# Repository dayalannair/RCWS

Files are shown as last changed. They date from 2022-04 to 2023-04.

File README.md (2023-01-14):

# Radar Intersection Collision Prediction System (R-ICPS)

### NB - Offline python proc exists in the folder

## TO DO

1. Modify Python algorithm with SOCA CFAR and PFa = 0.008
2. Get more IQ data
3. Test real time Python after update
4. Design chapter
5. Results chapter
6. Apply Lit review fixes after Yunus reviews

## Report notes

- Focus on MATLAB stuff in the 'advanced' directory of traingle FMCW DSP
- Add waterfall and other plot from pulse mean canceller and compare pre and post calibration
- finish up results, then either neaten or add to design and lit review
- Check with supervisors etc
- Rather have slightly more words than just on the verge of enough

## Task list

- [ ] Add all work to report - remember to use issues and discussions from old repo
- [X] Improve bin method by restricting 'search' area for triangle modulation/ I.e. based on fbd, where can we expect fbu?
- [X] Improve Python OS CFAR
- [X] Test full Python realtime version on PC and RPI
- [X] Integrate Pi camera and show real time plots of spectra, results, and video (similar to MATLAB offline processing)
- [X] Modify real time Python program to work with two uRADs
- [X] Modify dual radar Python program to incorporate two cameras. Pi can support one Pi cam and one USB camera
- [ ] Consider a Pi network - control and sensor nodes
- [ ] Create condensed Python program (no GUI) as required by the prototype
- [ ] Test system - both GUI and no GUI - on road side
- [ ] Install system on car and test in controlled and (or) road environments
- [ ] Neaten simulations and present in report
- [ ] clean up/neaten repository

### Link to data storage:
https://uctcloud-my.sharepoint.com/:f:/g/personal/nrxday001_myuct_ac_za/EjFL7omlg09PrdxWb3c22k4BgLi7pwkYM-8y16FP6_n1MA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

### Notes: 
- add data and library folders to MATLAB path after clone not needed if addpath() is called in each script
- Data collection/radar programs are in data/urad_usb
- make sure textfiles/data is never committed - deletion will not remove data from version history and so increase repo size
- in the event a repo gets too large, use filter-repo (3rd party program) to filter *.txt etc and push to a new repo
- USB for linux found using lsusb. Currently using ACM0. Device is infineon technologies

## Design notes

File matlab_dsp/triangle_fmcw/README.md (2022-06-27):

# Current state directory

This directory holds all of the latest/current files being tested/designed/used. This includes simulation (sm),
real data (rd), etc.

## cfar_sm --> Simulation using the CFAR detection algorithm
Note: the algorithm is still under test

The code outline follows:

1. Create radar object
2. Create target and environment objects
3. Simulation loop
    - Currently, the loop is run for a total of 1 second
    - the received echo is processed every t_step seconds
    - this means that in the intermediate intervals, the data is not observed, i.e. the target is made to hop
    from point to point, with a constant velocity
    - The simulation should be tested at the max update rate, which will generate a good amount of data
    - Decimation is used to simulate ADC sampling. The wave sample rate is related to the carrier as it needs
    to simulate this high freqeuncy.

4. Range and velocity estimates are plotted
5. Spectrums and signals plotted

## cfar_rd --> Real data processing using the CFAR detection algorithm
Similar to the above but for real data. Must use the data timestamps to get an average t_step time to use in simulation.
# Need to store data in an array before writing to file! and collect new data this way

## Rootmusic programs

These use the rootmusic algorithm instead of CFAR. Need to get it working on real data.

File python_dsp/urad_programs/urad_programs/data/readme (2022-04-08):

Data follows the following format:
Target number	Distance (m)	Velocity (m/s)	SNR (dB)

The file names correspond to the uRAD USB v1.2 and uRAD RPi v1.1 device measurements. Note that uRAD USB runs SDK 1.1 whereas uRAD RPi runs SDK v1.0.
Facing the device from the RPi power port, the uRAD USB is the left-hand side radar and the uRAD RPi is the right-hand side radar.
The program currently overwrites the last record session. If you would like to permanently save data, rename the file and/or copy to a different directory.

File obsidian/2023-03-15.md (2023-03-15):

- [ ] Add FFT length vs. accuracy scatters and table to results
- [ ] Update calibration section in impl - maybe remove section and add to another, since fairly straight fwd. 
- [ ] Get impl section reviewed
- [ ] Finish lit review comments - not pressing since they seem like QOL improvs
- [ ] Simons comments on simulation and method (see canvas)

If possible, get patch ant sim working. Else, phrase it better/dont give it a section in the sim section, maybe just add the antenna pattern plots.

# Important
1. Accuracy only important for controlled tests
2. Need GPS for controlled tests
3. Dependance on range accuracy more influential as range reduced. Opposite for velocity

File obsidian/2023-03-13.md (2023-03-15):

- [ ]  Implementation chapter reviewed
- [x] Continue with lit review and sim chapter corrections
- [ ] Add list of symbols
- [x] Get raw data for target at a known distance and post proc to test windowing and for calibration
	- [x] Or not since calib not dependent on window, though cannot analys windowing here
	- [ ] get a large set of points for calib!

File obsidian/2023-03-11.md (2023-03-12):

Need to apply report changes after new developments
- [x] Square law detector not on IQ samples
- [ ] DC cancelling on IQ samples
- [ ] change PFA with square law before CFAR
- [ ] window function need changes?
- [ ] Fix colour for BD matlab python engine
- [ ] CONTINUE with CFAR comparison
- [ ] 

- [x] Changes to Python proc as applied in matlab and test
	- [ ] Need to do more testing regarding nearest range bin and LHS targets
- [ ] Complete issues above and resolve comments in design section
- [ ] Read, resolve comments, Grammarly, print Implementation and submit
- [ ] Resolve comments on Lit review and simulation sections
- [ ] 

Field testing
- [x] apply angle adjustment condition to Python
- [ ] Test in controlled env near Peralex
- [ ] One last uncontrolled and photograph the setup
- [ ]

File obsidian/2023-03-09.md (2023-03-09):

Attempt ADC mean cancellation - uRAD GUI line 611
Need to test with more data
continue addressing comments on design chapter, then pass through Grammarly and print
Address comments on other sections before sorting out the implementation section
Dont forget about the ADT sim data
And add code for AOA left side, and ensure cuter angle not needed - doubt since now all dets on left of boresight - may be able to prove 25 deg is optimal

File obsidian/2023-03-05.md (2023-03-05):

Adding printed changes to simulation section
Need to add frame sync rtproc and iq_data versions - not strictly, would be nice
One more controlled test
	- UCT
	- Somewhere else
Add new tables to the simulation section (cross over) and continue cleaning

Angle correction wrong in matlab - need to check that angle corrected values are larger than measurement

RT proc not looking good. Present offline proc results using new heatmap scheme
	- #### NB not looking good for raised tests

Video frame rate higher/faster in rt proc than iq. Likely 4thd vs 2thd. Use 2 thd iq data collection next time. 
	- Makes sense since video in same thd as radar? should be the other way round?
	- 
	Add option to record offline proc and store in data repo. Then dont need to reproc each time

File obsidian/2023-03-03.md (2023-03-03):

Note that the best rhs result is 03-03-2023: _12_52_43
- Add that to the report
- check left side
- note that this was not placed on the car

Check if placing radar on car better or worse
	- device was further from the edge of the road

Continue prepping sim section for review
Finish up results section and send for review
Then clean up implementation and design

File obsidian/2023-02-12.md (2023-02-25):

### Session 1:

- Installing Fusion360 to get CAD renderings
- Created a reduced comments file of Yunus' doc
- Lit review and methodology have the most comments to be addressed, so continue with those
- Since system works with angle adjustment, need to add adjustment to the test rig, get final set of road data and present in results section. 
- WOuld be good to get a final set of controlled results at UCT
	- Need GPS tracks + radar + speedometer
- Remember to report on the improved measurements using angle conrrections

### Session 2:

- added some info to lit review on SA statistics
- need to find analysis on intersection statistics
- need to inprove the bits from the RTMC
- added and sorted out CAD rendering in report

#### Session 3:

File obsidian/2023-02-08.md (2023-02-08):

Added the equations for the sawtooth calcs for the speed v range trade off.
	Need to refine by adding explanation
	Need to neaten and add velocity equation
	Add code snippet
Added Simon's comments here. Need to address these and Yunus' comments
Need to test different angle from left side radar tomorrow
	should be enough battery power

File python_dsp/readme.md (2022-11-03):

# Results

## offline processing

### Offline plotting raw data
- the returns of cars passing directly infront or close to the radar have a broad SNR when the Taylor window is implemented. 
- Most of the easy to see targets in the spectra are those moving away after passing the host 
- need to test Hanning window
- Many targets/ a busy road will affect detection and tracking
- add offline processing to confirm

## Real time results

Sparse due to many reflective targets
Wind?

## Call matlab engine

This can only run on a PC with MATLAB installed. The Python script reads in data from the uRAD/s and stores in a MATLAB workspace. A MATLAB processing script is called to process the data. Results are read from the workspace.

### 1. Configurable MATLAB workspace parameters
This option allows for changing the MATLAB parameters from within the Python script.

### 2. Preconfigured MATLAB workspace
A MATLAB script is used to generate all of the required variables beforehand, which are saved as a .mat file. The Python script loads this file instead of calling MATLAB functions to generate the base parameters.

### Note
The MATLAB engine takes a couple of seconds to boot

## Python plots

- These plot out the real time DSP and results thereof. 
- The plotting slows down processing
- VNC remote desktop runs very slowly
- SSH X forwarding runs slowly
- Storing as a JPEG is slow, though faster than the above methods

## Store results

- No plotting, though data is stored in arrays and finally written to a textfile. 
- Minimal effect on performance, though not as optimal as the full realtime system (no plot, no store)

## Pure system

- Only the final results are displayed.
- Results displayed in the CLI or using LEDs
- PWM to be implemented

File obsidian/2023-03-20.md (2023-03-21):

1. Simulation section
	1. For simulating patch antenna, it seems that one needs to get the microstrip design correct, and the taper must be set. In the meantime, can still attempt to get it going. 
	2. Need to address the comments on this chapter first. Leave microstrip for last
2. Results
	1. Prep section for final results
	2. Get RPI ready for final results
		1. Can measure performance/update rate so long

# 2023-03-21

Need to change proc to be in terms of 1024-point FFT

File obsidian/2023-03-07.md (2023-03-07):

[[2023-03-06]] See stuff thats here

1. Address both Yunus and Simons comments on Simulation section
	1. Look through the comments for lit review and simulation to see if anything major needs to be addressed.
2. If all is good with above, get design chapter ready for review
	1. Go through latex doc
	2. Grammarly
	3. Print and read through + edit
3. Once design chapter in for review, address comments to lit review and simulation chapters
4. Get final results
	1. add check for AOA based on angle adjustment and test outside work
	2. More controlled experiments
	3. One more uncontrolled - take PICTURES for both
	4. Write up section and send for review
5. Lastly, get implementation section reviewed
6. Get overall impression, then get whole thing reviewed one more time.

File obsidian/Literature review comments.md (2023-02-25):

Things to do:

1. More south african context - move from intro 
2. Current systems - summarise functionality and how well they work. Also costs
3. V2I 
	1. Strengths + assumptions
	2. weaknesses
4. V2V
	1. strengths + assumptions
	2. weaknesses
5. Standalone
	1. radar tracking
		1. key params of the radar
	2. Clarify link between Kalman: 
		1. Gate method
		2. Tracking is needed~
6. #### Crit review
	1. Clear link 
	2. highlight weaknesses
3. #### Automotive radar system
	Factors contributing to performance and ref - need to find out if ref sections or cite. think the former

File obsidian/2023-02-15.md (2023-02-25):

Remember to mention how Python program is structured: 
	All variants pull from a common processing library

Did admin for ethics and prog report

Continue in the afternoon on comments
printing general papers on V2V and V2I

## Comments for Yunus to address:

- I believe the paragraphs detailing collision warning and assistance covers functionality?
- The next paragraph explains conditions in which performance is reduced

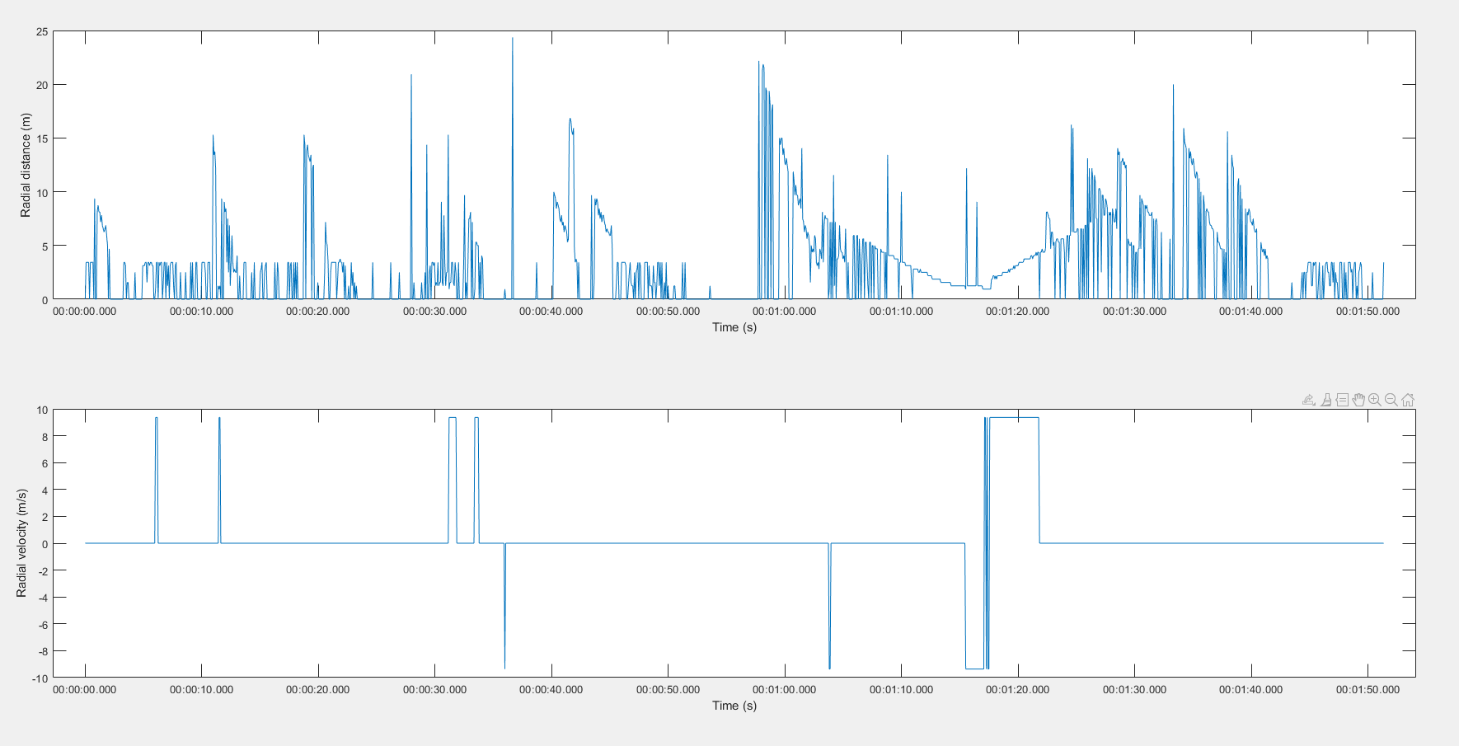
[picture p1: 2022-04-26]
python_dsp/urad_programs/graphs/mydsp_mti_gui.png

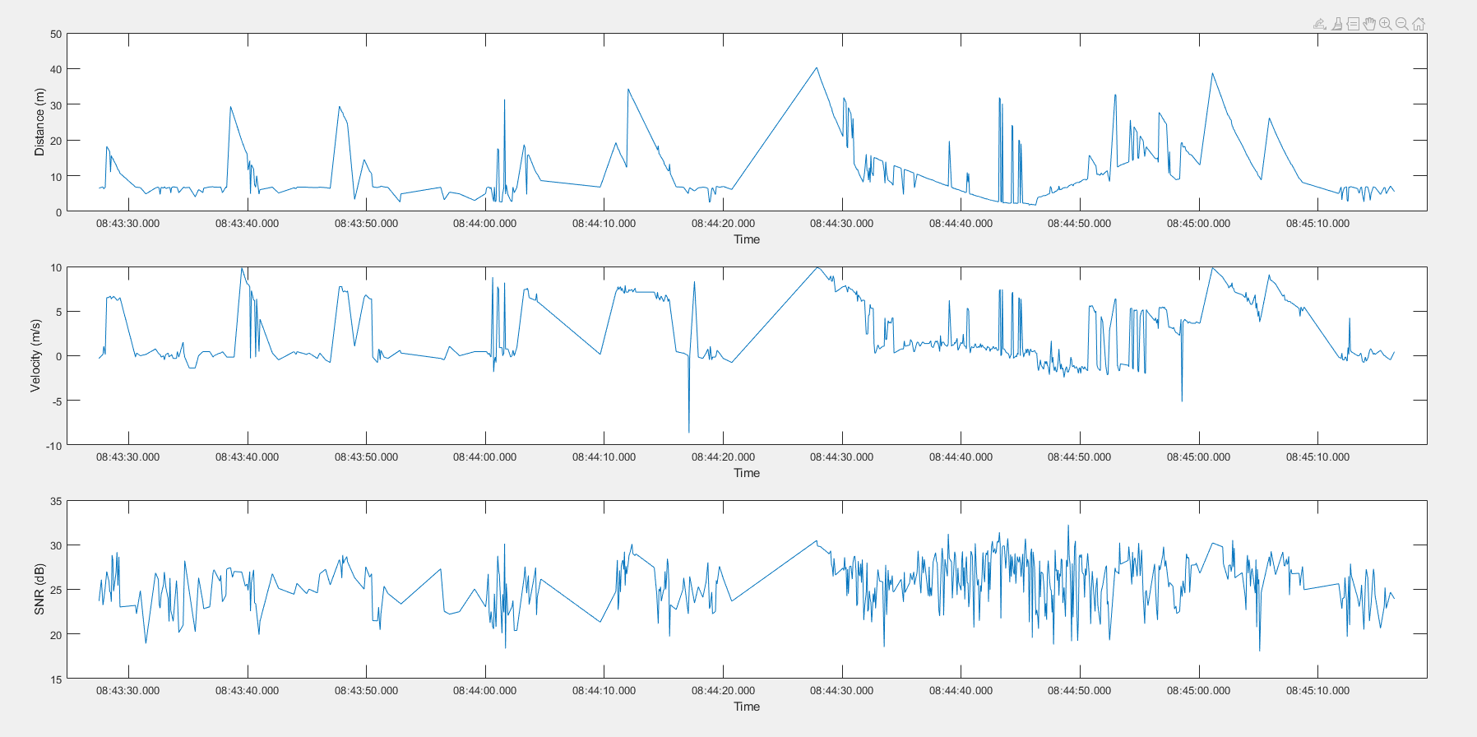
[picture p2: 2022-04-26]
python_dsp/urad_programs/graphs/urad_dsp_mti_gui.png

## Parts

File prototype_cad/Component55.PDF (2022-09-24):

SOLIDWORKS Student Edition. For Academic Use Only.

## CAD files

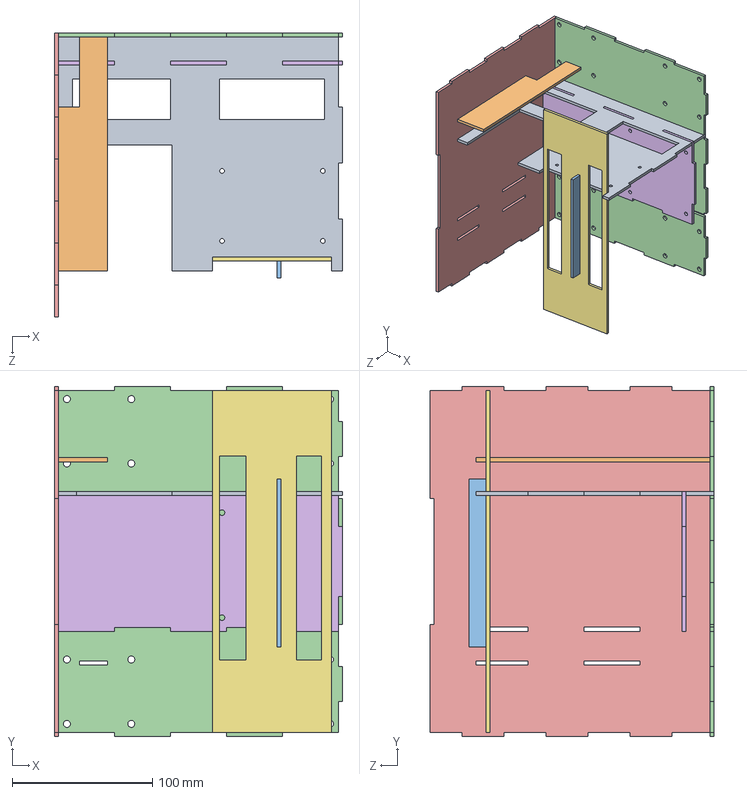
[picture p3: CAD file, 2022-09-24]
prototype_cad/prototype1_ICPS v98.SLDASM
206.0 x 250.0 x 203.0 mm
cam_secure
bottom
back
pi_holder
cam_holder (1)

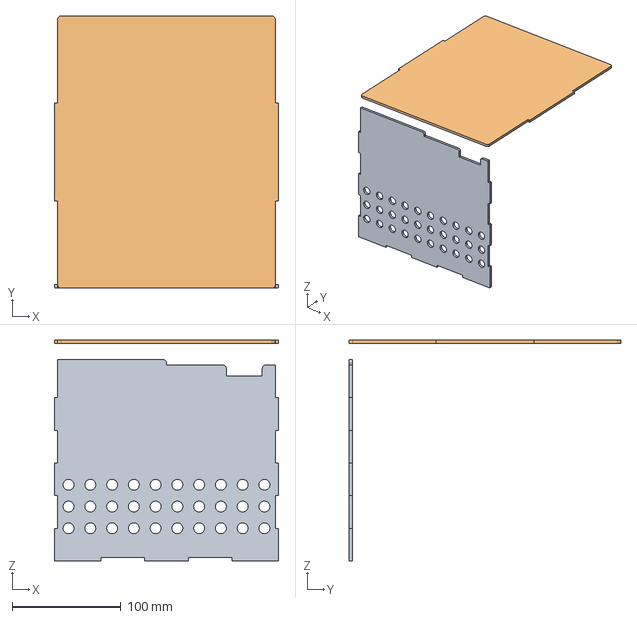
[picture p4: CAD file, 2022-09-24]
prototype_cad/top_and_side.step
206.0 x 250.0 x 203.0 mm
right
top

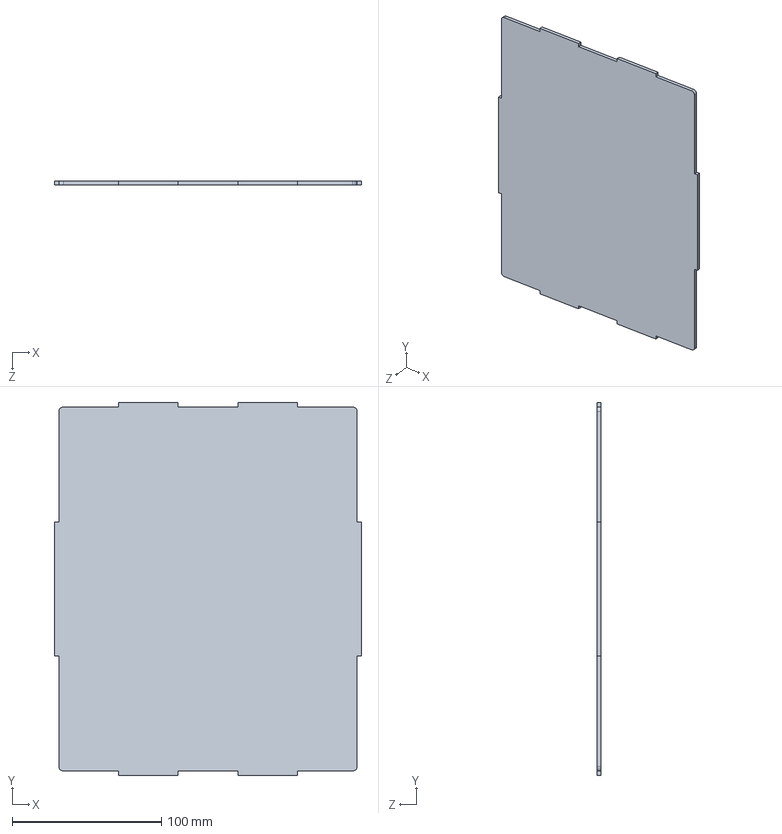
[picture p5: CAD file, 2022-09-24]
prototype_cad/top new.SLDPRT
206.0 x 250.0 x 3.00 mm

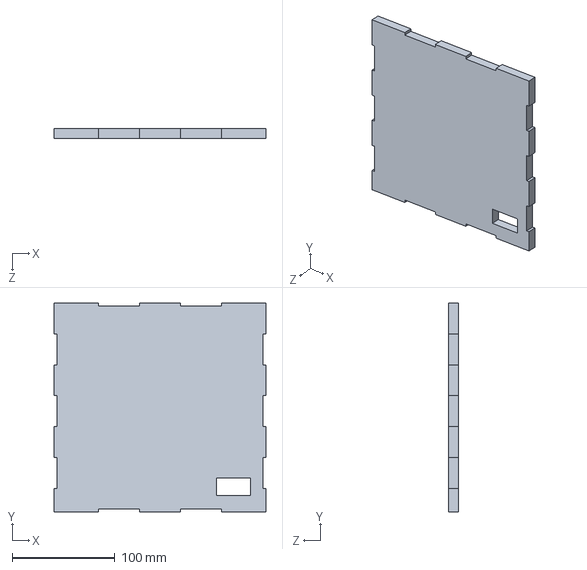
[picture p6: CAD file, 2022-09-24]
prototype_cad/side.SLDPRT
206.0 x 203.0 x 10.0 mm

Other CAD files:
prototype_cad/rails.sldasm
prototype_cad/pi_holder.sldprt
prototype_cad/cam_holder (1).sldprt
prototype_cad/back.sldprt
prototype_cad/right.sldprt
prototype_cad/top.sldprt
prototype_cad/cam_secure.sldprt
prototype_cad/Component55.sldprt
prototype_cad/Component54.sldprt
prototype_cad/bottom.sldprt
prototype_cad/Component54.SLDDRW
prototype_cad/Component55.SLDDRW
prototype_cad/back.SLDDRW
prototype_cad/bottom.SLDDRW
prototype_cad/cam_holder (1).SLDDRW
prototype_cad/cam_secure.SLDDRW
prototype_cad/side.SLDDRW
prototype_cad/top new.DXF
prototype_cad/top new.SLDDRW
prototype_cad/top_and_side.SLDASM

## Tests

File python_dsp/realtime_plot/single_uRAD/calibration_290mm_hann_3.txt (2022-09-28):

1.5920351119281047
1.8369635906862747
2.0818920694444447
1.8369635906862747
1.9594278300653596
4.041319899509804
3.5514629419934636
2.6942132663398697
1.9594278300653596
2.326820548202615
3.1840702238562093
2.326820548202615
3.4289987026143787
2.326820548202615
3.673927181372549
1.5920351119281047
1.9594278300653596
1.9594278300653596
1.8369635906862747
2.2043563088235296
1.8369635906862747
1.9594278300653596

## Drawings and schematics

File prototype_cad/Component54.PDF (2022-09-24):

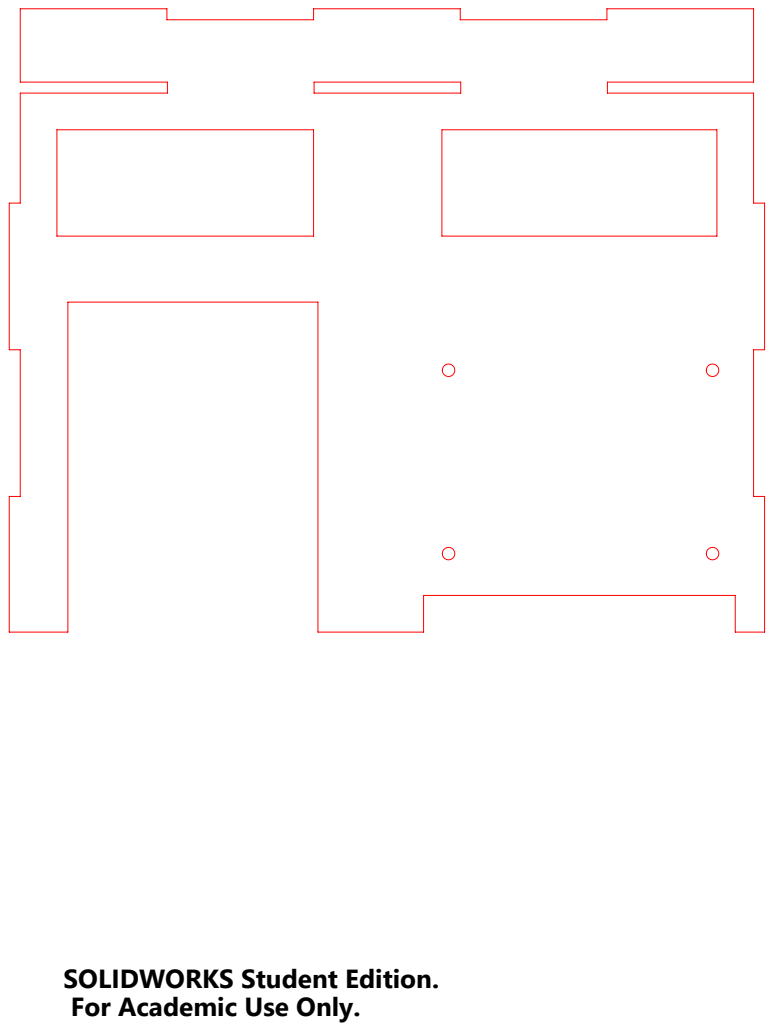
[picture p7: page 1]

SOLIDWORKS Student Edition.
For Academic Use Only.

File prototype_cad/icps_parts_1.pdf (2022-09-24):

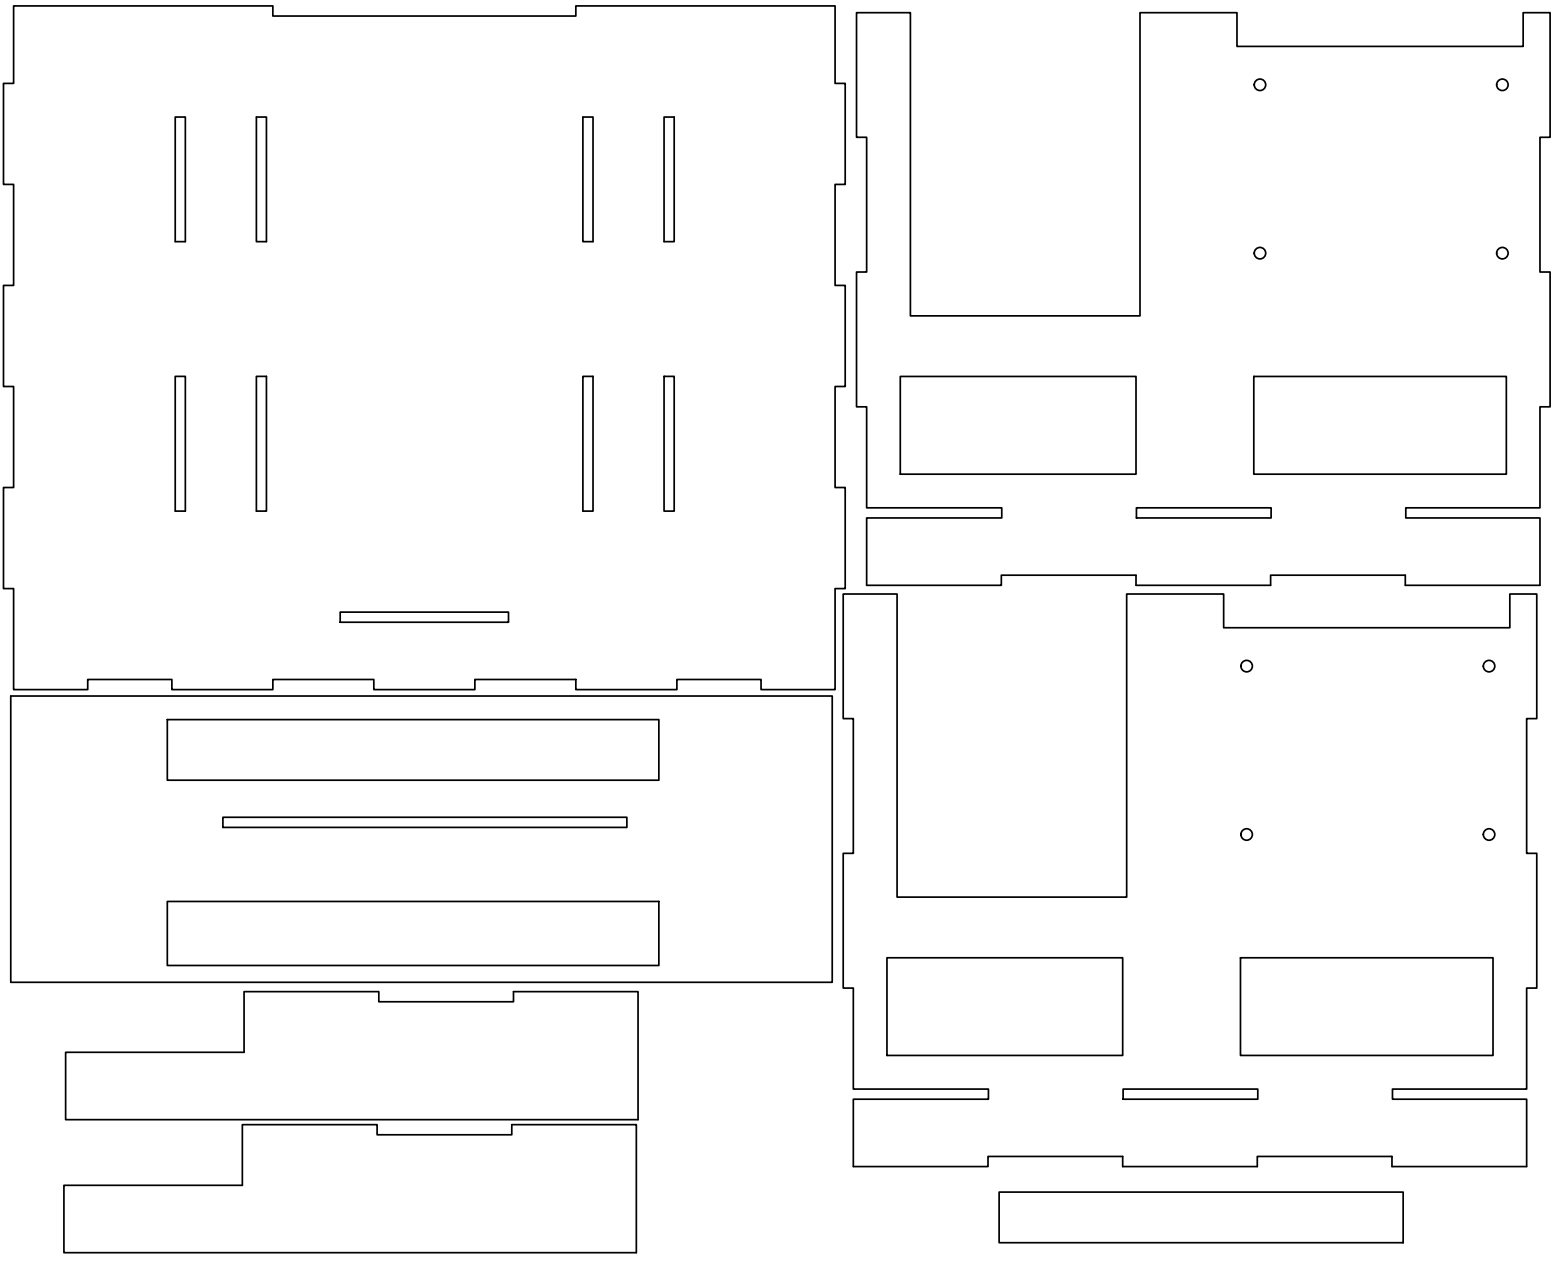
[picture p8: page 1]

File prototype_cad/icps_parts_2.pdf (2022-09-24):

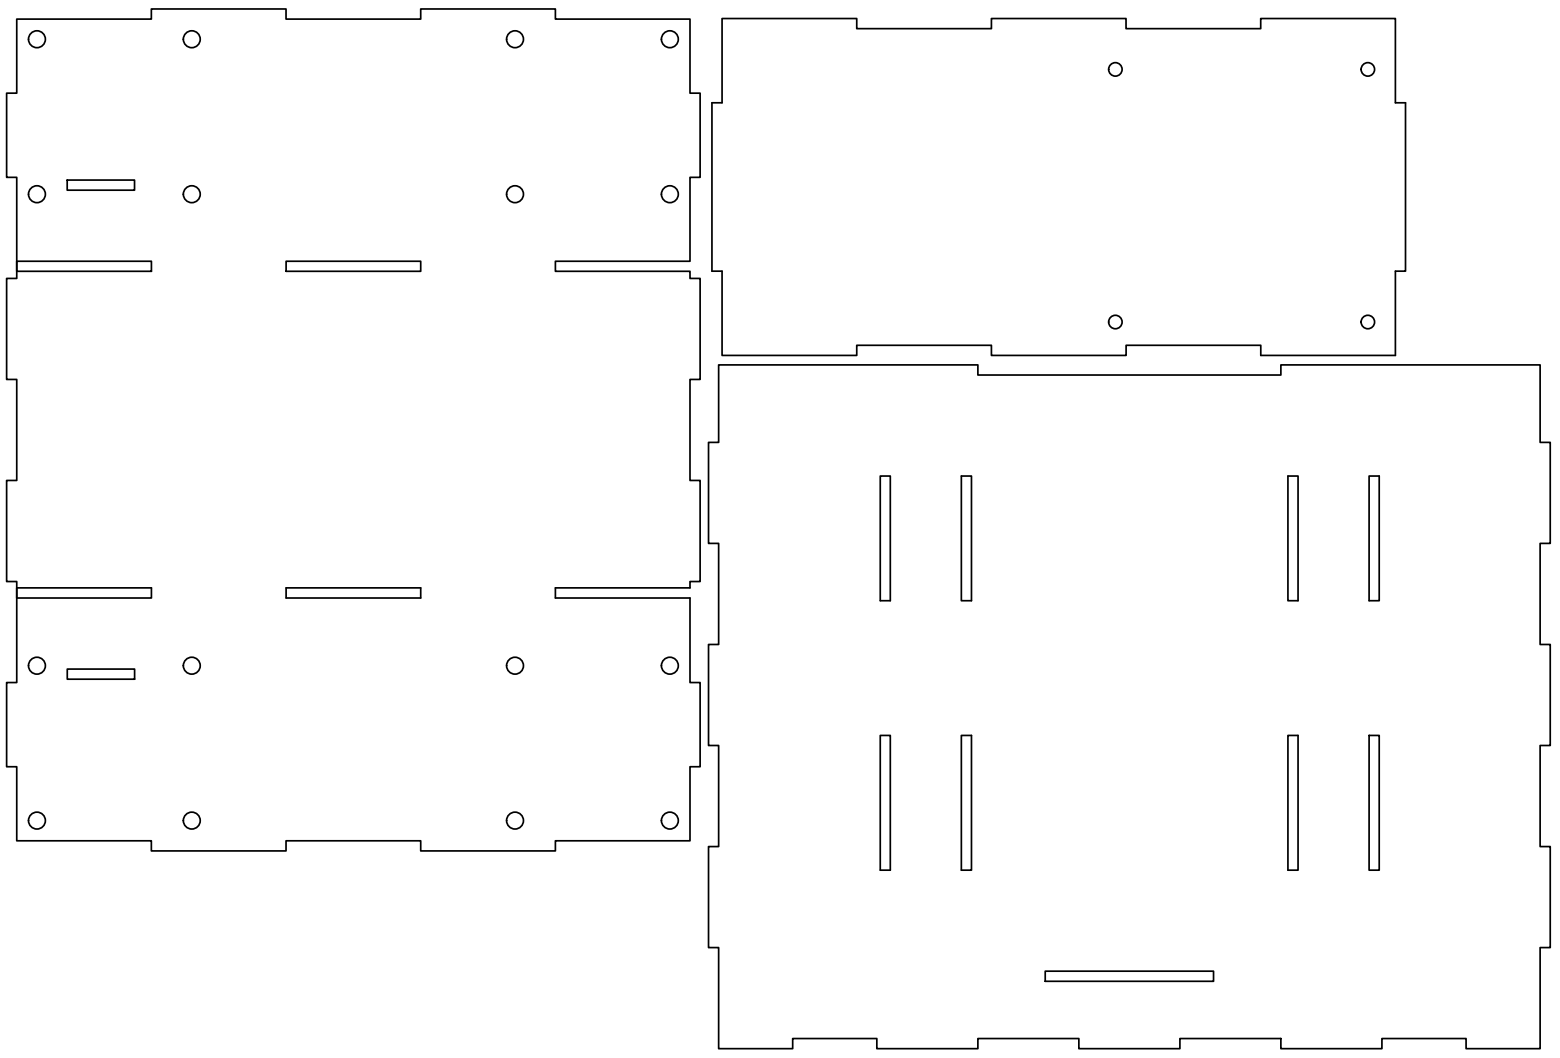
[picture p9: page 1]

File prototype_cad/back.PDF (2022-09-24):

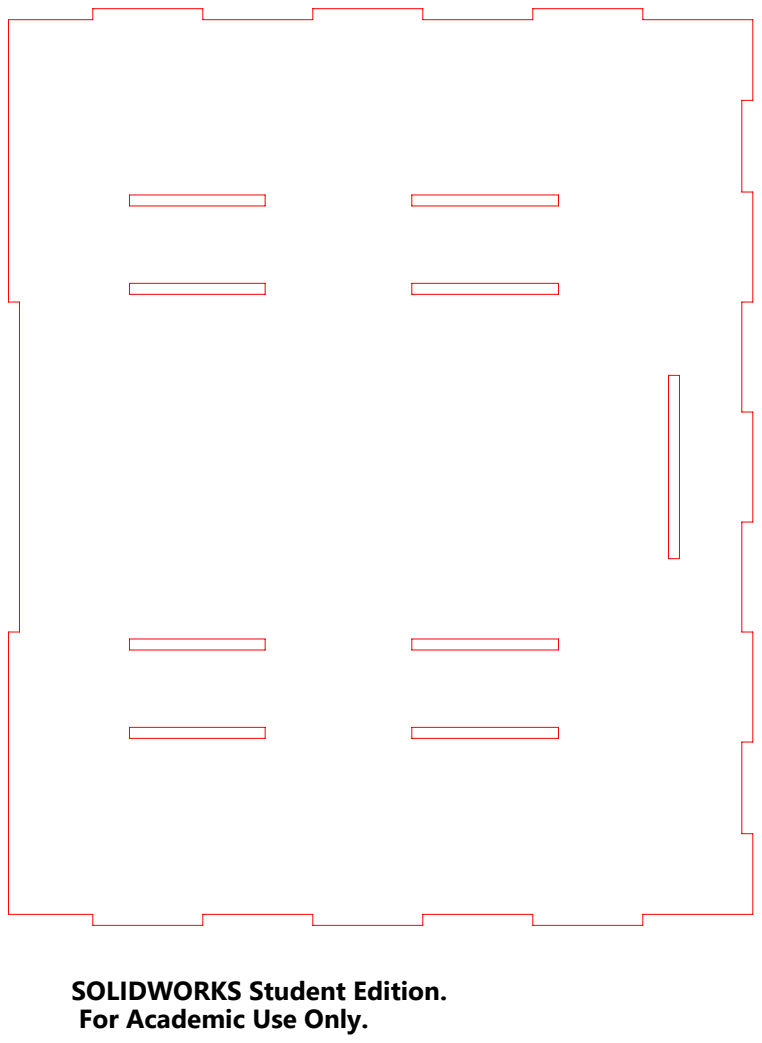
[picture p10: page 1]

SOLIDWORKS Student Edition.
For Academic Use Only.

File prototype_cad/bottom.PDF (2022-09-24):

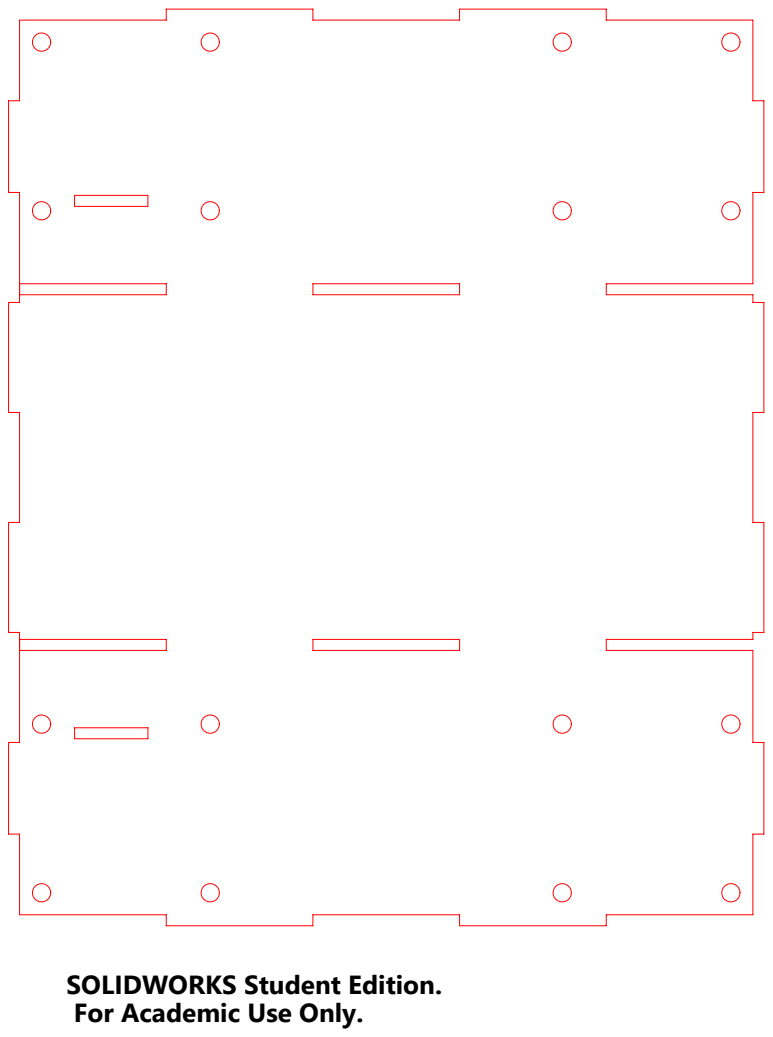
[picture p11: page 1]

SOLIDWORKS Student Edition.
For Academic Use Only.

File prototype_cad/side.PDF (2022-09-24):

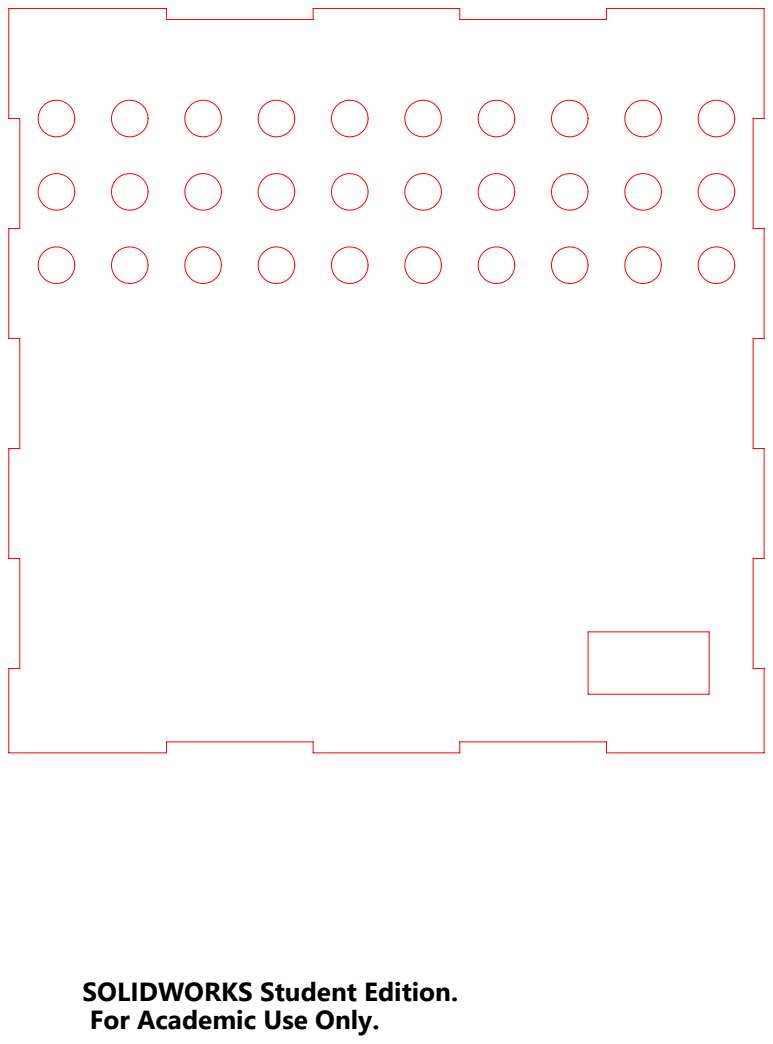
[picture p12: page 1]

SOLIDWORKS Student Edition.
For Academic Use Only.

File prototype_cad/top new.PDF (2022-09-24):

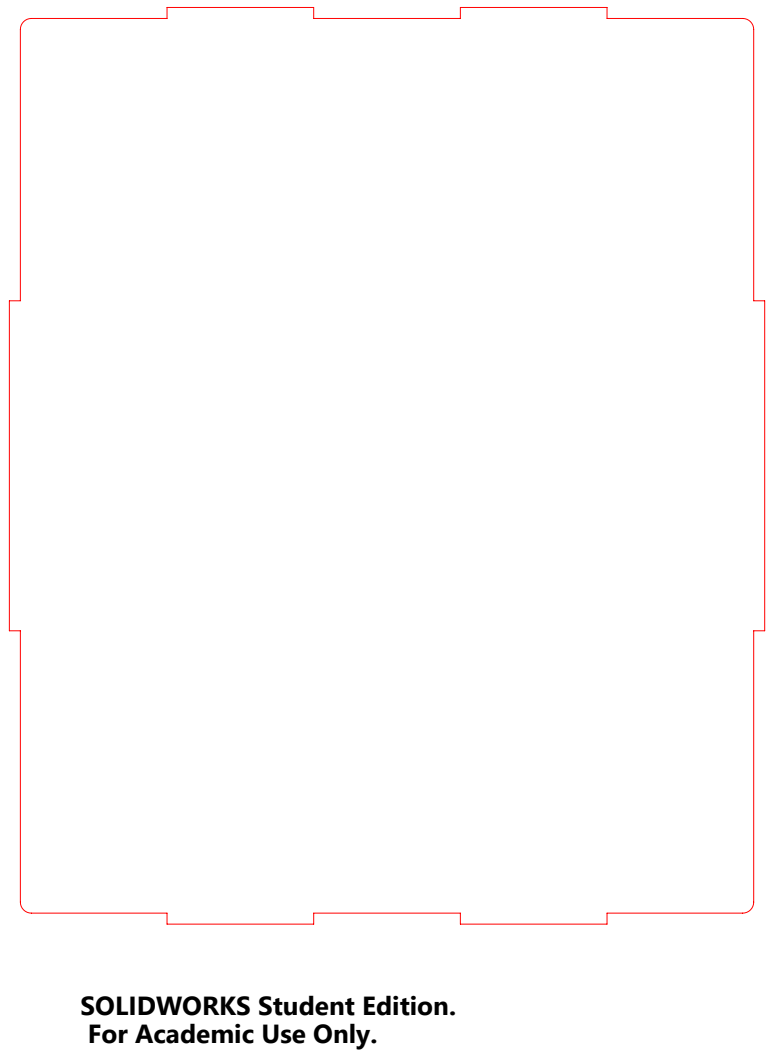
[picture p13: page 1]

SOLIDWORKS Student Edition.
For Academic Use Only.

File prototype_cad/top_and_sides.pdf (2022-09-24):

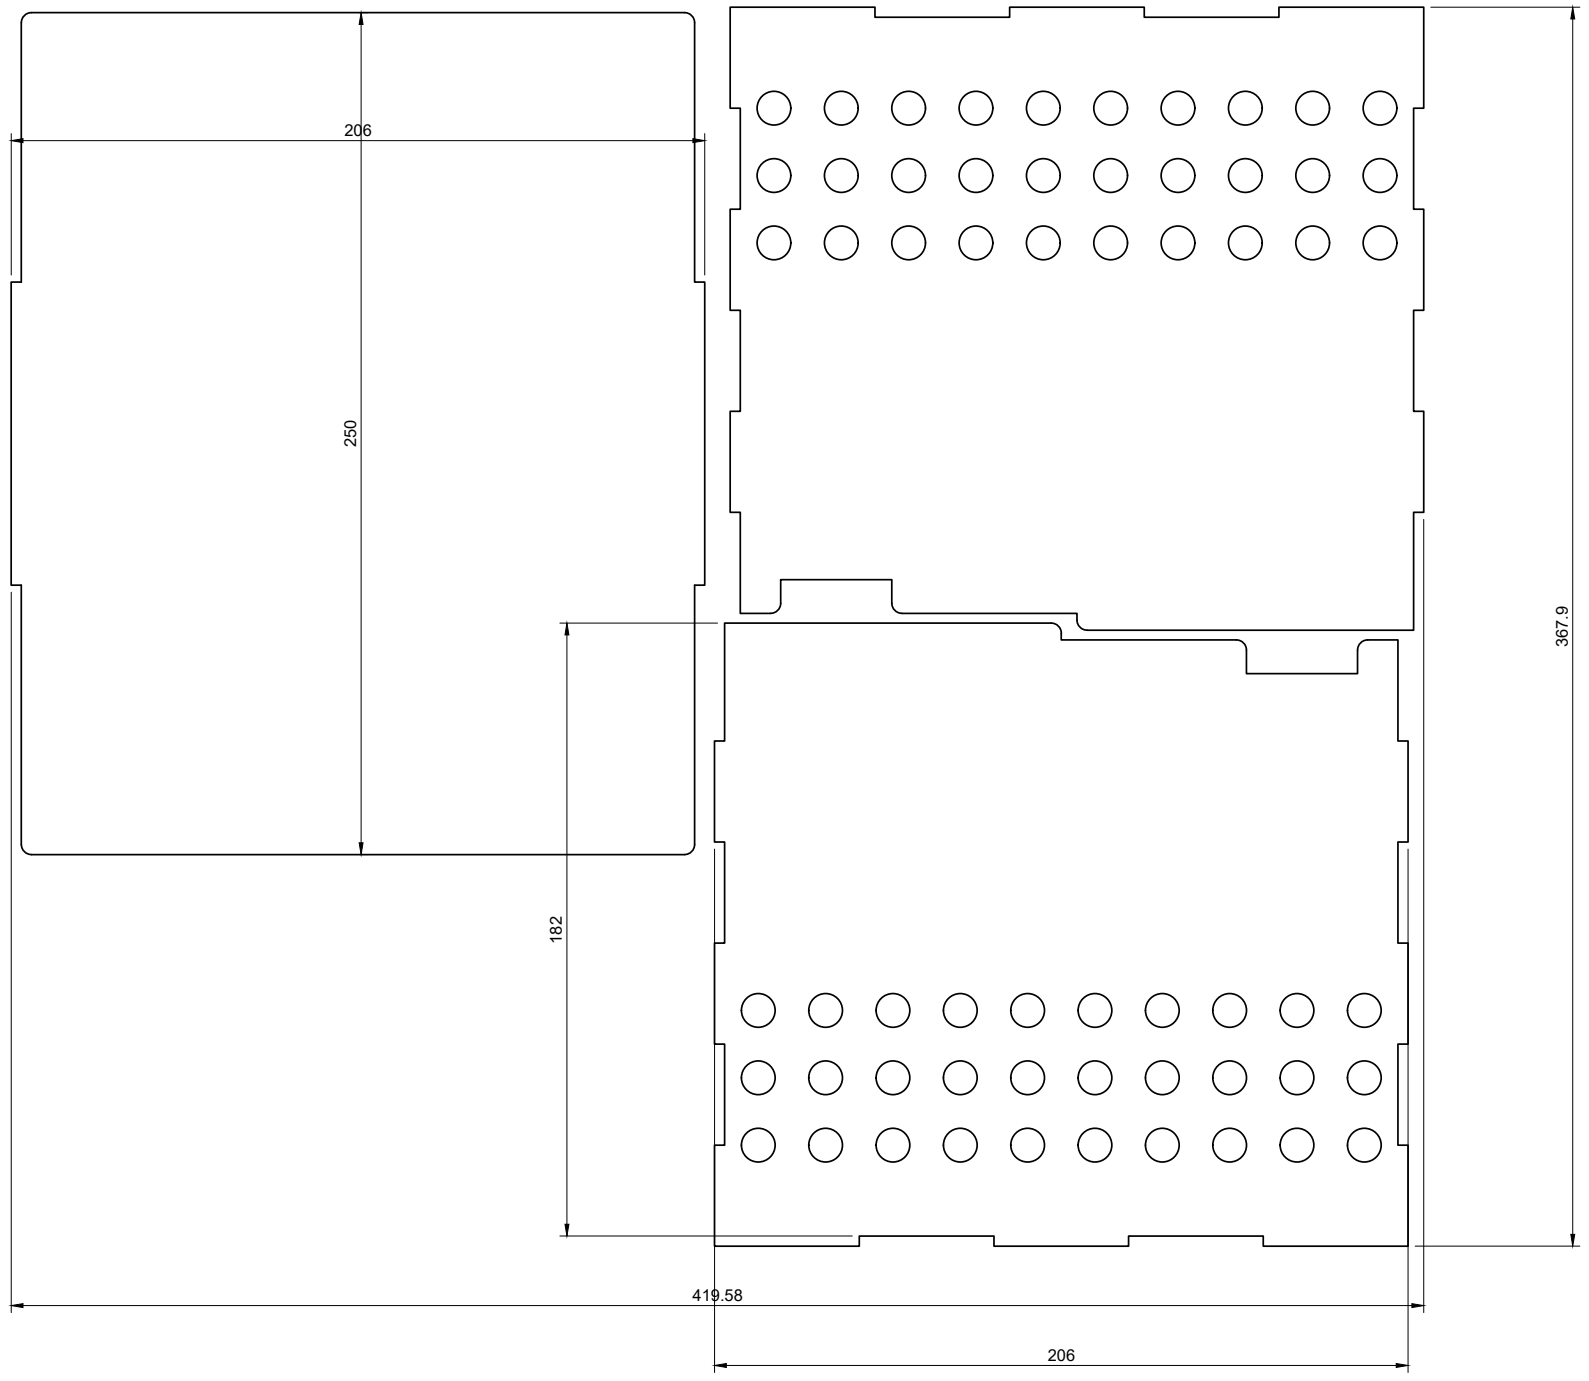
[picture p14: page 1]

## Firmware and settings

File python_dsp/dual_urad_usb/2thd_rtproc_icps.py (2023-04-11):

# Each thread runs a camera and uRAD USB

import sys
sys.path.append('../custom_modules')
import os
import uRAD_USB_SDK11
import serial
from time import time, sleep, strftime,localtime
import sys
from pyDSPv2 import py_trig_dsp
import numpy as np
import cv2
from scipy import signal
import threading

# True if USB, False if UART
usb_communication = True

try:
	mode_in = str(sys.argv[1])
	BW = int(sys.argv[2])
	Ns = int(sys.argv[3])
	duration = int(sys.argv[4])
	Pfa = float(sys.argv[5])
	t = localtime()
	now = strftime("%H_%M_%S", t)  
	fs = 200000
	# runtime = sweeps*Ns/200000
	if mode_in == "s":
		print("********** SAWTOOTH MODE **********")
		resultsFileName = 'IQ_saw_' + str(BW) + '_' + str(Ns) +  '_' + str(now) + '.txt'
		mode = 2					
	elif mode_in == "t":
		print("********** TRIANGLE MODE **********")
		resultsFileName = 'IQ_tri_' + str(BW) + '_' + str(Ns) + '_' + str(now) + '.txt'
		mode = 3	
	elif mode_in == "d":
		print("********** DUAL RATE MODE **********")
		resultsFileName = 'IQ_dual_' + str(BW) + '_' + str(Ns) + '_' + str(now) + '.txt'
		mode = 4					
	else: 
		print("Invalid mode")
		exit()
	# print("BW = ",str(BW),"\nNs = ",str(Ns),"\nSweeps = ",str(sweeps))
	# print("Expected run time (saw): ",str(runtime))
except: 
	print("Invalid mode")
	exit()
ns = 200 # bypass user input
SOS = ns*(Pfa**(-1/ns)-1)
print("Pfa: ", str(Pfa))
print("CFAR alpha value: ", SOS)
# input parameters
# BW and Ns input as arguments
f0 = 5						# starting at 24.005 GHz
I_true = True 				# In-Phase Component (RAW data) requested
Q_true = True 				# Quadrature Component (RAW data) requested

# Serial Port configuration
ser1 = serial.Serial()
if (usb_communication):
	# ser1.port = 'COM3'
	ser1.port = '/dev/ttyACM0'
	ser1.baudrate = 1e6
else:
	print("Could not find USB 1 connection.")
	exit()

ser2 = serial.Serial()
if (usb_communication):
	# ser1.port = 'COM3'
	ser2.port = '/dev/ttyACM1'
	ser2.baudrate = 1e6
else:
	print("Could not find USB 2 connection.")
	exit()

# Sleep Time (seconds) between iterations
timeSleep = 5e-3

# Other serial parameters
ser1.bytesize = serial.EIGHTBITS
ser1.parity = serial.PARITY_NONE
ser1.stopbits = serial.STOPBITS_ONE
ser1.timeout = 1

ser2.bytesize = serial.EIGHTBITS
ser2.parity = serial.PARITY_NONE
ser2.stopbits = serial.STOPBITS_ONE
ser2.timeout = 1

def closeProgram():
	# switch OFF uRAD
	return_code1 = uRAD_USB_SDK11.turnOFF(ser1)
	return_code2 = uRAD_USB_SDK11.turnOFF(ser2)
	if (return_code1 != 0 or return_code2 != 0):
		print("ERROR: Ending")
		exit()

# Open serial port
try:
	ser1.open()
except:
	print("COM port 1 failed to open")
	closeProgram()

try:
	ser2.open()
except:
	print("COM port 2 failed to open")
	closeProgram()

# switch ON uRAD
return_code = uRAD_USB_SDK11.turnON(ser1)
if (return_code != 0):
	print("uRAD 1 failed to turn on")
	closeProgram()

return_code = uRAD_USB_SDK11.turnON(ser2)
if (return_code != 0):
	print("uRAD 2 failed to turn on")
	closeProgram()


if (not usb_communication):
	sleep(timeSleep)

# loadConfiguration uRAD
return_code = uRAD_USB_SDK11.loadConfiguration(ser1, mode, f0, \
	BW, Ns, 0, 0, 0, 0, 0, 0, 0, 0, I_true, Q_true, 0)
if (return_code != 0):
	print("uRAD 1 configuration failed")
	closeProgram()

return_code = uRAD_USB_SDK11.loadConfiguration(ser2, mode, f0, \
	BW, Ns, 0, 0, 0, 0, 0, 0, 0, 0, I_true, Q_true, 0)
if (return_code != 0):
	print("uRAD 2 configuration failed")
	closeProgram()

if (not usb_communication):
	sleep(timeSleep)

# Poll radar to test if working correctly
return_code, results, raw_results = uRAD_USB_SDK11.detection(ser1)
if (return_code != 0):
	print("Error requesting data from uRAD 1")
	closeProgram()

return_code, results, raw_results = uRAD_USB_SDK11.detection(ser2)
if (return_code != 0):
	print("Error requesting data from uRAD 2")
	closeProgram()
print("Radars configured")
# Radar parameters
fs = 200e3
n_fft = 1024
c = 299792458
tsweep = 1e-3
bw = 240e6
slope = bw/tsweep
# DC cancellation
max_voltage = 3.3
ADC_bits = 12
ADC_intervals = 2**ADC_bits
numVoltageLevels = max_voltage/ADC_intervals

# Processing parameters
half_train = 16
half_guard = 14

nbins = 16
scan_width = 32
calib = 0.9837
win = signal.windows.taylor(ns, nbar=3, sll=40, norm=False)
bin_width = round((n_fft/2)/nbins)
print("Bin width: ", str(bin_width))

# System parameters
# NOTE: comment out which is not being used!
# Right radar angle correction
road_width = 9
rhs_road_width = round(road_width/4)
angOffsetMinRangeRhs = 100 
# Left radar angle adjustment and correction
lhs_road_width = round(3*road_width/4)
angOffsetMinRangeLhs = 7.1 

angOffset = 25*np.pi/180

# frequency axes
# positive axis contains 0 Hz
fpos = np.linspace(0, round(fs/2)-1, round(n_fft/2))
# negative axis flipped about y axis
fneg = np.linspace(round(fs/n_fft), round(fs/2), round(n_fft/2))

# For plots
rngAxPos = c*fpos/(2*slope)
rngAxNeg = c*fneg/(2*slope)

# ======================= CAMERAS ================================
cap1 = cv2.VideoCapture(0)
cap2 = cv2.VideoCapture(2)

cap1.set(3, 320)
cap1.set(4, 240)

cap2.set(3, 320)
cap2.set(4, 240)

fourcc  = cv2.VideoWriter_fourcc(*'X264')
lhs_vid = cv2.VideoWriter('2thd_lhs_vid_'+now+'_rtproc.avi',fourcc, 30.0, (320,240))
rhs_vid = cv2.VideoWriter('2thd_rhs_vid_'+now+'_rtproc.avi',fourcc, 30.0, (320,240))

# Burst captures expected to be around 30 seconds long
n_rows = 3000
# rg_array = np.zeros([n_rows, nbins], dtype=int)
# sp_array = np.zeros([n_rows, nbins], dtype=int)
# sf_array = np.zeros([n_rows, nbins], dtype=int)

# rg_array_2 = np.zeros([n_rows, nbins], dtype=int)
# sp_array_2 = np.zeros([n_rows, nbins], dtype=int)
# sf_array_2 = np.zeros([n_rows, nbins], dtype=int)
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

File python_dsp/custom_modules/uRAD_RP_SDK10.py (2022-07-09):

# uRAD_RP_SDK10.py - Library for controlling uRAD SHIELD
# Created by Victor Torres, Diego Gaston - uRAD 2018

import spidev
from time import sleep, time
from gpiozero import OutputDevice
import struct
import math

PinTurnOn = OutputDevice(17)
SlaveSelect = OutputDevice(27)
PinTurnOn.off()
SlaveSelect.off()

spi = spidev.SpiDev() # Create spi object
spi_speed = 1000000

def turnON():
	PinTurnOn.on()

def turnOFF():
	PinTurnOn.off()

def loadConfiguration(mode, f0, BW, Ns, Ntar, Rmax, MTI, Mth):
	
	global configuration
	configuration = [0] * 8
	global NtarMax
	NtarMax = 5
	f0Min = 5
	f0Max = 195
	f0Max_CW = 245
	BWMin = 50
	BWMax = 240
	NsMin = 50
	NsMax = 200
	RmaxMax = 100
	VmaxMax = 75

	# Check correct values
	if ((mode == 0) or (mode > 4)): 
		mode = 3
	if ((f0 > f0Max) and (mode != 1)):
		f0 = f0Min
	elif ((f0 > f0Max_CW) and (mode == 1)):
		f0 = f0Min
	elif (f0 < f0Min):
		f0 = f0Min
	BW_available = BWMax - f0 + f0Min;
	if ((BW < BWMin) or (BW > BW_available)):
		BW = BW_available
	if ((Ns < NsMin) or (Ns > NsMax)):
		Ns = NsMax
	if ((Ntar == 0) or (Ntar > NtarMax)):
		Ntar = 1
	if ((mode != 1) and ((Rmax < 1) or (Rmax > RmaxMax))):
		Rmax = RmaxMax
	elif ((mode == 1) and (Rmax > VmaxMax)):
		Rmax = VmaxMax
	if (MTI > 1):
		MTI = 0
	if ((Mth == 0) or Mth > 4):
		Mth = 4
	Mth -= 1
	
	# Create configuration register
	configuration[0] = ((mode << 5) + (f0 >> 3)) & 0b11111111
	configuration[1] = ((f0 << 5) + (BW >> 3)) & 0b11111111
	configuration[2] = ((BW << 5) + (Ns >> 3)) & 0b11111111
	configuration[3] = ((Ns << 5) + (Ntar << 2) + (Rmax >> 6)) & 0b11111111
	configuration[4] = ((Rmax << 2) + MTI) & 0b11111111 
	configuration[5] = (Mth << 6) + 0b00100000
	configuration[6] = 0
			
def detection(distance, velocity, SNR, bufferI, bufferQ, movement):

	# Variables
	code_configuration = [227]
	code_isready = [204]
	code_results = [199]
	code_I = [156]
	code_Q = [51]
	ACK = 170
	buff_temp = [0] * 4
	tx_1byte = [0]
	tx_results = [0] * (NtarMax*3*4+2)
	results = [0] * (NtarMax*3*4+2)
	error = False
	read_timeout = 0.200
	
	# SPI configuration
	spi.open(0,0) # open spi port 0, device (CS) 0
	spi.max_speed_hz = spi_speed
	spi.mode = 0b01 # mode of operation 0b[CPOL][CPHA]
	SlaveSelect.on()
	
	# Send configuration to uRAD
	configuration[6] = 0
	if (distance != 0):
		configuration[6] = 0b10000000
	if (velocity != 0):
		configuration[6] = configuration[6] + 0b01000000
	if (SNR != 0):
		configuration[6] = configuration[6] + 0b00100000
	if (bufferI != 0):
		configuration[6] = configuration[6] + 0b00010000
	if (bufferQ != 0):
		configuration[6] = configuration[6] + 0b00001000
	if (movement != 0):
		configuration[6] = configuration[6] + 0b00000100
	
	CRC = ((configuration[0] + configuration[1] + configuration[2] + configuration[3] + configuration[4] + configuration[5] + configuration[6])) & 0b11111111
	configuration[7] = CRC
	
	# Send configuration by SPI
	rx_ACK = [0]
	t0 = time()
	ti = time()
	while ((rx_ACK[0] != ACK) and ((ti-t0) < read_timeout)):
		SlaveSelect.off()
		sleep(0.0005)
		spi.xfer([code_configuration[0]])
		sleep(0.0005)
		spi.xfer([configuration[0], configuration[1], configuration[2], configuration[3], configuration[4], configuration[5], configuration[6], configuration[7]])
		sleep(0.0015)
		rx_ACK = spi.xfer(tx_1byte)
		SlaveSelect.on()
		sleep(0.0005)
		ti = time()

	if ((ti-t0) >= read_timeout):
		error = True
	if (distance != 0 or velocity != 0 or SNR != 0 or movement != 0):
		sleep(0.0200)

	if not error:
		rx_ACK = [0]
		while ((rx_ACK[0] != ACK) and ((ti-t0) < read_timeout)):
			SlaveSelect.off()
			#sleep(0.0010)
			spi.xfer([code_isready[0]])
			sleep(0.0015)
			rx_ACK = spi.xfer(tx_1byte)
			SlaveSelect.on()
			#sleep(0.0010)
			ti = time()

		if ((ti-t0) >= read_timeout):
			error = True
		
		if not error:

			configuration[5] = configuration[5] & 0b11011111;
			
			# Receive results
			if (distance != 0 or velocity != 0 or SNR != 0 or movement != 0):
				
				SlaveSelect.off()
				sleep(0.0005)
				spi.xfer([code_results[0]])
				sleep(0.0005)
				results = spi.xfer(tx_results)
				SlaveSelect.on()

				Ntar_temp = (configuration[3] & 0b00011100) >> 2
				for i in range(Ntar_temp):
					if (distance != 0):
						buff_temp[0] = results[i*4]
						buff_temp[1] = results[i*4+1]
						buff_temp[2] = results[i*4+2]
						buff_temp[3] = results[i*4+3]
						buff_temp_bytes = bytearray(buff_temp)
						temp = struct.unpack('<f', buff_temp_bytes)
						distance[i] = temp[0]
					if (velocity != 0):
						buff_temp[0] = results[NtarMax*4+i*4]
						buff_temp[1] = results[NtarMax*4+i*4+1]
						buff_temp[2] = results[NtarMax*4+i*4+2]
						buff_temp[3] = results[NtarMax*4+i*4+3]
						buff_temp_bytes = bytearray(buff_temp)
						temp = struct.unpack('<f', buff_temp_bytes)
						velocity[i] = temp[0]
					if (SNR != 0):
						buff_temp[0] = results[NtarMax*8+i*4]
						buff_temp[1] = results[NtarMax*8+i*4+1]
						buff_temp[2] = results[NtarMax*8+i*4+2]
						buff_temp[3] = results[NtarMax*8+i*4+3]
						buff_temp_bytes = bytearray(buff_temp)
						temp = struct.unpack('<f', buff_temp_bytes)
						SNR[i] = temp[0]
				if (movement != 0):
					if (results[NtarMax*12] == 255):
						movement[0] = True
					else:
						movement[0] = False

			mode_temp = (configuration[0] & 0b11100000) >> 5
			Ns_temp = ((configuration[2] & 0b00011111) << 3) + ((configuration[3] & 0b11100000) >> 5)
			if (mode_temp == 3):
				Ns_temp = 2 * Ns_temp
			elif (mode_temp == 4):
				Ns_temp = 2 * Ns_temp + 2 * math.ceil(0.75 * Ns_temp)

			# Receive I,Q
			tx_bufferIQ = [0] * (2 * Ns_temp)
			if (bufferI != 0):
				SlaveSelect.off()
				sleep(0.0005)
				spi.xfer([code_I[0]])
				sleep(0.0005)
				bufferI_SPI = spi.xfer(tx_bufferIQ)
				SlaveSelect.on()
				for i in range(Ns_temp):
					bufferI[i] = (bufferI_SPI[2*i+1] << 8) + bufferI_SPI[2*i]

			if (bufferQ != 0):
				SlaveSelect.off()
				sleep(0.0005)
				spi.xfer([code_Q[0]])
				sleep(0.0005)
				bufferQ_SPI = spi.xfer(tx_bufferIQ)
				SlaveSelect.on()
				for i in range(Ns_temp):
					bufferQ[i] = (bufferQ_SPI[2*i+1] << 8) + bufferQ_SPI[2*i]
		else:
			configuration[5] = configuration[5] & 0b11011111
			configuration[5] += 0b00100000
	else:
		configuration[5] = configuration[5] & 0b11011111
		configuration[5] += 0b00100000
	spi.close()
	return error

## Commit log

2022-04-20 velocity processing
2022-04-21 dsp velocity
2022-06-12 added calcs for rd coupling and rmax
2022-07-03 neatened current state directory
2022-07-03 commented out timer. not nb and not precise
2022-07-05 Radial velocity axis added with proof
2022-07-10 added mode switching
2022-07-17 camera. hopefully git ignore works
2022-07-19 thread and clean
2022-07-19 threaded cam and urad
2022-07-19 threaded working
2022-08-15 fixed for up and down store
    [dual_uRAD_store_raw.py]
2022-08-17 Working threaded 2 cam 2 radar
2022-08-17 Good wip. see 2 thread version
2022-08-18 Timed threads python
2022-08-18 Working 4 and single thread
2022-08-23 good wip forwarding tight vnc
    [dual_uRAD_cams_plot_blit.py, dual_uRAD_plot_blit.py, dual_uRAD_plot_blit_raw.py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]
2022-09-11 CAD data for prototype enclosure
    [Component54.SLDDRW, Component54.sldprt, Component55.SLDDRW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]
2022-09-28 calibration testing
2022-09-28 good wip calibrating old data
2022-09-28 calibration confirmed for all data sets for driveby
2022-10-20 modified dual raw threaded capture for two urad usbs
2022-10-29 Neatened calibration plots
2022-11-03 fixes pre road recording test
    [iq_data_icps.py]
2022-11-05 added 2 thread variant
2022-12-06 Added new gate bounds. needs debug. Improved Pfa and reversed imagesc plot x axis as needed
2023-01-05 continue ADC on laptop and add figs to report
2023-01-22 Fixed issue with waterfall and data, see fbu and fbd to solve same Dopp issue
    [pyDSPv2.py]
2023-01-28 Python proc improved. Time of arrival calc fixed.
    [CFAR.py, pyDSPv2.py]
2023-01-28 attempted plotting another set and doing fancy things with path init. ran into error in result proc
    [load_data_lib.py]
2023-03-05 Updated plotting for results and other fixes.
    [2thd_rtproc_icps.py, load_data_lib.py, pyDSPv2.py]
2023-03-10 updates to visualisers after adding complex FFT, using correct window operation, and adding DC filter
2023-03-11 updated python proc for ang offset and corrected windowing and SLD
    [pyDSPv2.py]
2023-03-14 calibration tests. Need to ensure fft 0Hz correct
2023-03-18 calibration and fft N comparison.
2023-03-19 window testing in matlab for furthest range detection. Updated cmap and fixes to python offline dsp
    [load_data_lib.py]
2023-03-19 more testing and updating of plots. Average V is correct
    [load_data_lib.py, pyDSPv2.py]
2023-03-21 Found that prealloc array for timestamps crashes cam and reduces radar update rate. reverted to Python list
    [2thd_rtproc_icps.py, 4thd_iq_data_icps.py, 4thd_rtproc_icps.py]
2023-03-27 checked data for 25 deg correction. Going to use 18 deg
    [load_data_lib.py]
2023-03-27 Tested update rates for thread variations and for uRAD Pi 1.1 and USB v1.2
2023-03-30 updates: exit when camera fails
    [2thd_iq_data_icps.py, 2thd_rtproc_icps.py, 4thd_iq_data_icps.py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]
2023-04-06 2thd rt proc tested on pi, bug solved. 2thd performance equivalent to 1 thd, so 1 thd not updated
    [2thd_rtproc_icps.py]
2023-04-07 Update lane width and angle correction
    [load_data_lib.py, pyDSPv2.py]
2023-04-11 final results and fixed vid frame rate for rt proc
    [2thd_rtproc_icps.py, load_data_lib.py, plot_rtproc.py]
